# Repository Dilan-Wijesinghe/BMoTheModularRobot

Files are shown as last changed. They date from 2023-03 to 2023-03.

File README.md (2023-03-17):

# BMo
Winter Project for my MS in Robotics Winter Quarter!

Video Demonstration (https://www.youtube.com/watch?v=KZacVYFTs9U)

All Modules

### Project Description
BMo is a modular robot consisting of three distinct modules, the brain (BMo), motor (MMo), and hinge (HMo) modules. By connecting these modules in a different configurations, BMo can transform into several different robots. BMo was inspired by the modular robotics kits I had as a child, and was a challenge to myself to do a very intensive hardware project with almost zero experience.

This repository contains the code accompanying BMo.
It also includes the final CAD files I used to create each module.

BMo in a 'Crab' Configuration

### Hardware
Below is the boards used, and the magnetic connector that made everything possible
* [Adafruit Feather RP2040](https://www.adafruit.com/product/4884)
* [Adafruit Feather ESP32](https://www.adafruit.com/product/3591)
* [Magnetic Pogo Pin](https://www.adafruit.com/product/5413)

### Uploading Code
To upload code onto the RP2040 boards, hold down the BOOTSEL button while inserting a USB-C from your PC.
This should pop open a drive called 'RPI-RP2' onto your PC. From here you can use the Arduino IDE to upload the 
code. 

Note the pins used during setup(), as these pins determine where communication is sent. 
SCL and SDA are used for i2c communication, while pins 26 or 20 are used for servo control.

### Central.io (Brain)
This file contains code necessary for running the central or 'brain' of BMo. It sends i2c messages received 
from the Serial port in order to communicate with the rest of the modules. 
Once the code is loaded, use `screen` or the serial port in the Arduino IDE to send messages.

### Sender.io (Wireless Serial)
This file contains half of the code for the central 'brain' and allows wireless communication through the
ESP32 NOW peer-to-peer protocol. This half uses the serial port to send commands wirelessly to a receiver
board located inside BMo. To connect the sender to the receiver, you need to have both of their MAC
addresses, which can be found by using `WiFi.macAddress()`

### Receiver.io (Wirless Brain)
The file contains the other half of the central 'brain'. It takes the commands from the sender and 
sends them to any of the connected peripherals along its i2c bus. 

### Peripheral.io (Motor Module)
This file contains code necessary for running the peripheral or main 'motor' module, MMo. It receives
i2c messages from the brain and moves according to the given command. By default, `i` moves the servo inside
the module clockwise, while `k` moves it counter-clockwise. Pressing `j` will stop the motor.

To remap, modify the if statements to your desired mapping.

### HMo.io (Hinge Module)
This file contains code necessary for running the peripheral module, HMo. In the same way MMo receives and interprets messages, so
does HMo. Currently, the `e`, `w`, and `q` are mapped to one 0, 90, and 180 degrees.

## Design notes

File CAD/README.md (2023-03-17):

### Building BMO
This folder contains the necessary files in order to build each module. Each piece is laser 
cut on a 1/8" acrylic piece and press-fit together. For additional strength, I added super glue 
to a few of the walls, but left at least two openings to fix any internal electrical issues.

Each of the subfolders contains images of the layout of each module, which can serve 
as a guide to put them all together.

Let's get building!

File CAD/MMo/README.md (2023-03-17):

### MMo Build Guide
In order to construct MMo, go through a similar process as 
BMo and HMo by cutting out each part on your laser cutter. Each piece connects together
as depicted in the image below. 

MMoSkeletonCropped

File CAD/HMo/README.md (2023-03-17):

### HMo Build Guide
In order to construct HMo, go through a similar process as 
BMo and cut out each part on your laser cutter. Each piece connects together
as depicted in the image below. 

HMoSkeletonCropped

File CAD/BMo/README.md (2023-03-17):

### BMo Build Guide
In order to construct BMo, cut out each part on your laser cutter. You will need to
cut out the Bot/Top wall twice, as well as the Right/Left wall, since they are identical.
Here is how they should look. 

BMoSkeletonCropped

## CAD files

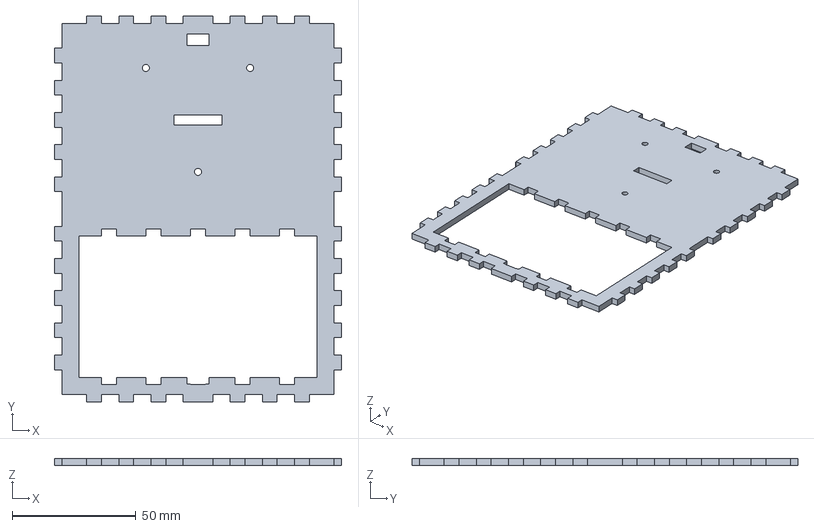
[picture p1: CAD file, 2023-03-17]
CAD/BMo/Bmo Top.step
116.0 x 156.0 x 3.00 mm

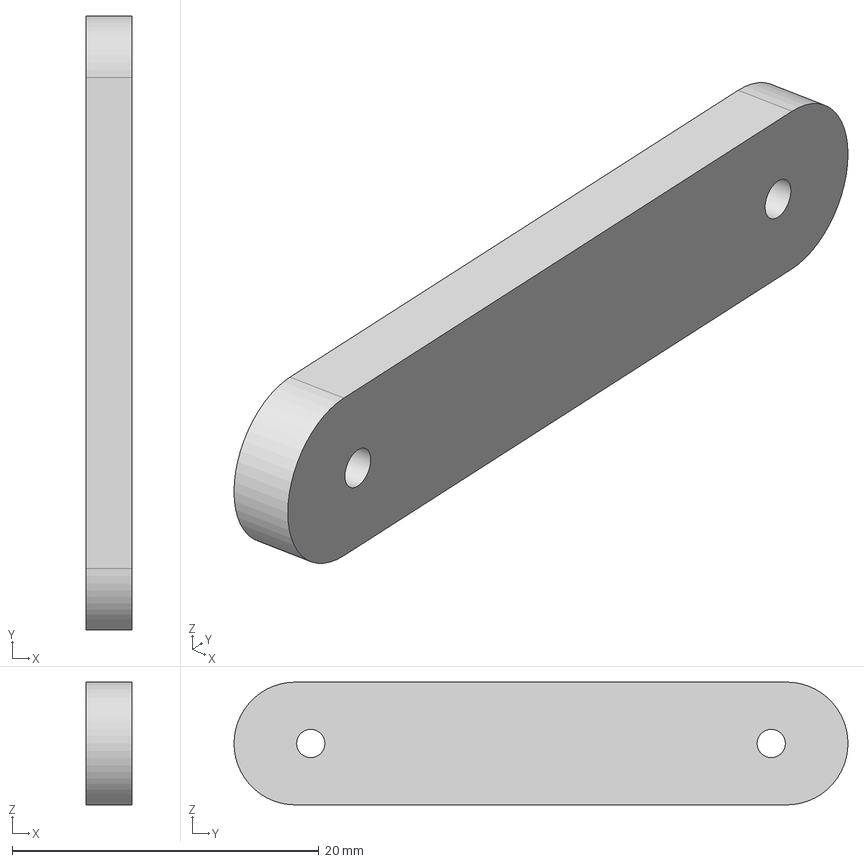
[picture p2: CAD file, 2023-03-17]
CAD/HMo/Hmo_Bracket.step
3.00 x 40.0 x 8.00 mm

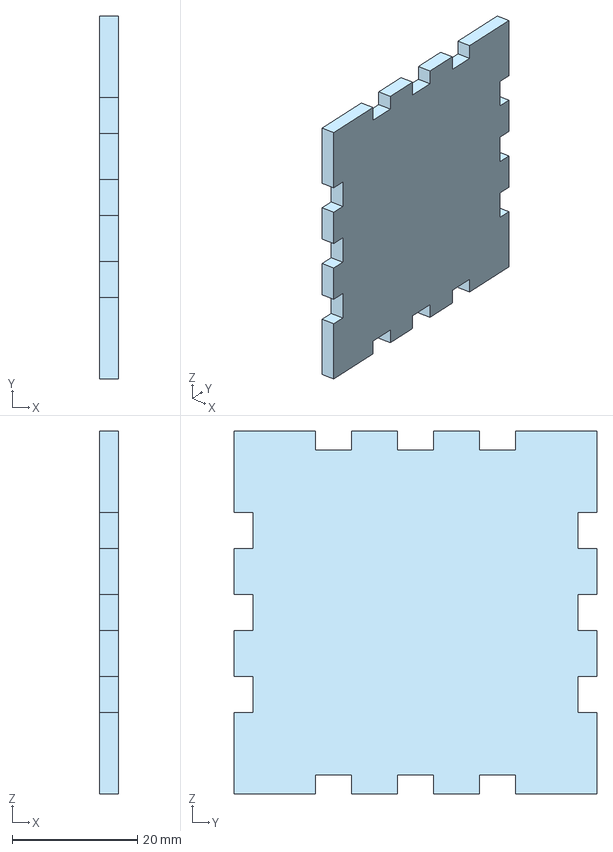
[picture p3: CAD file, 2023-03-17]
CAD/MMo/Mmo_right_wall.step
3.00 x 58.0 x 58.0 mm

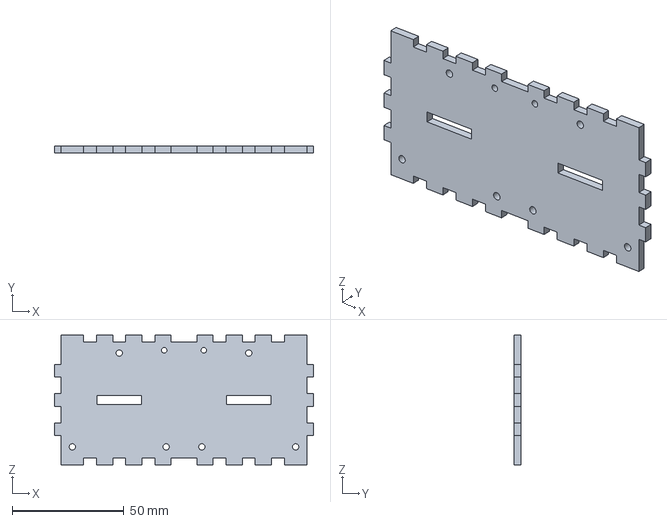
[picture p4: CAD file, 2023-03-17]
CAD/BMo/Bmo BotTop Wall.step
116.0 x 3.00 x 58.0 mm

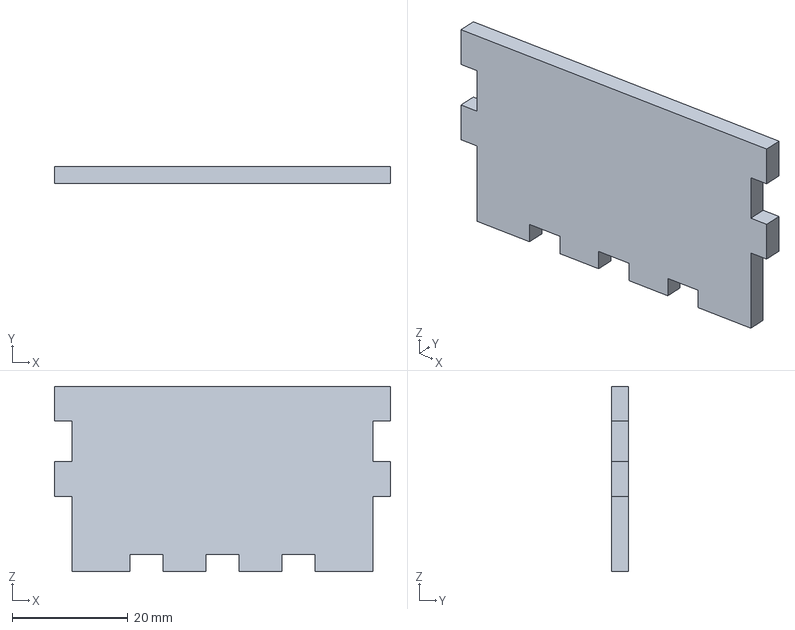
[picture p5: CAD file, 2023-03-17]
CAD/HMo/Hmo_Bot_Wall.step
58.0 x 3.00 x 32.0 mm

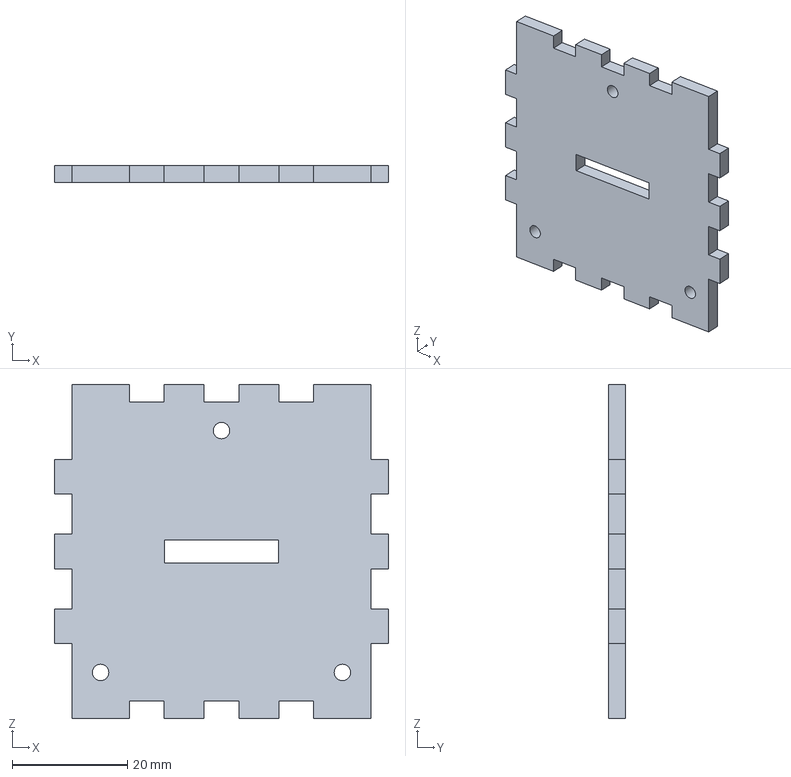
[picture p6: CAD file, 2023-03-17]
CAD/MMo/Mmo_top_wall.step
58.0 x 3.00 x 58.0 mm

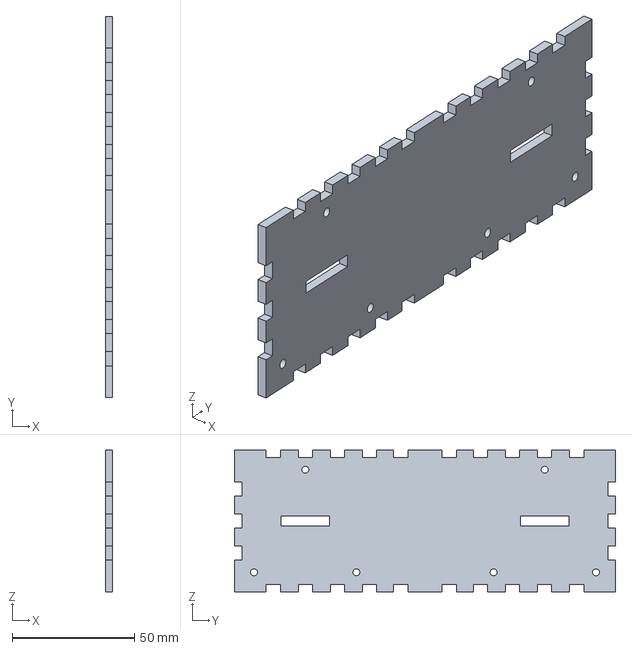
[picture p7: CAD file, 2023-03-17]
CAD/BMo/Bmo RightLeft Wall.step
3.00 x 156.0 x 58.0 mm

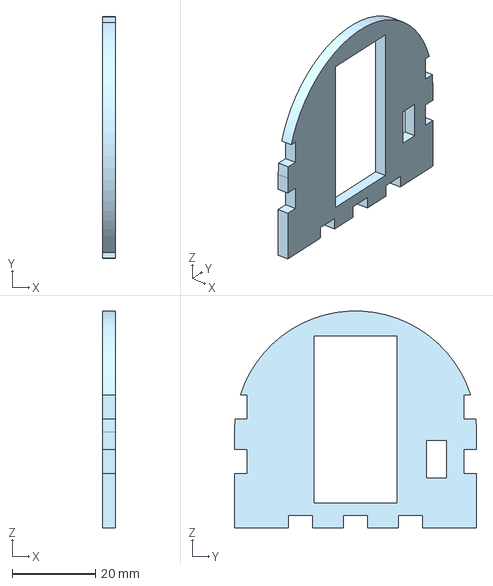
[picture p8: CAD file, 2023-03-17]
CAD/HMo/Hmo_Left_Wall.step
3.00 x 58.0 x 52.0 mm

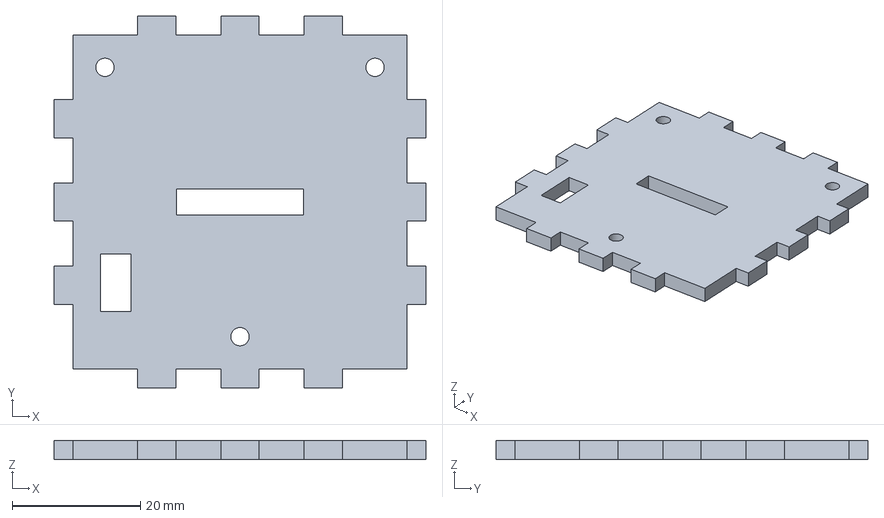
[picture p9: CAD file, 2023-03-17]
CAD/MMo/Mmo_bot.step
58.0 x 58.0 x 3.00 mm

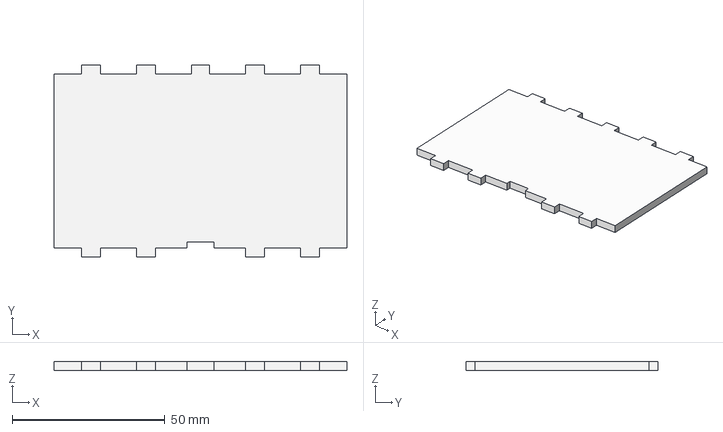
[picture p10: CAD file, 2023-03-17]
CAD/BMo/Bmo Face.step
96.0 x 63.0 x 3.00 mm

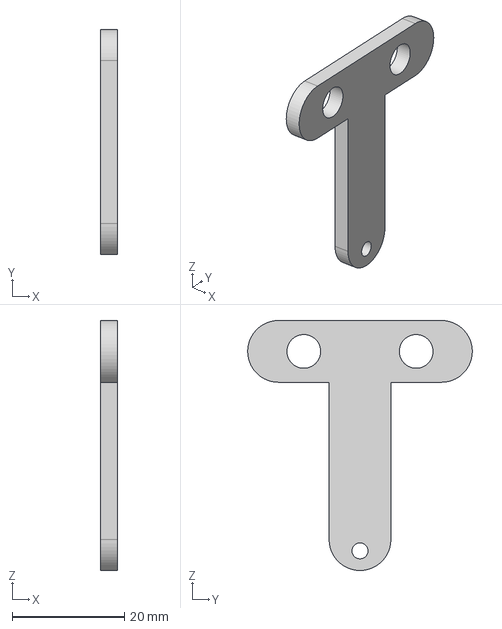
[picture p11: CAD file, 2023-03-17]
CAD/HMo/Hmo_Arm.step
3.00 x 40.0 x 44.5 mm

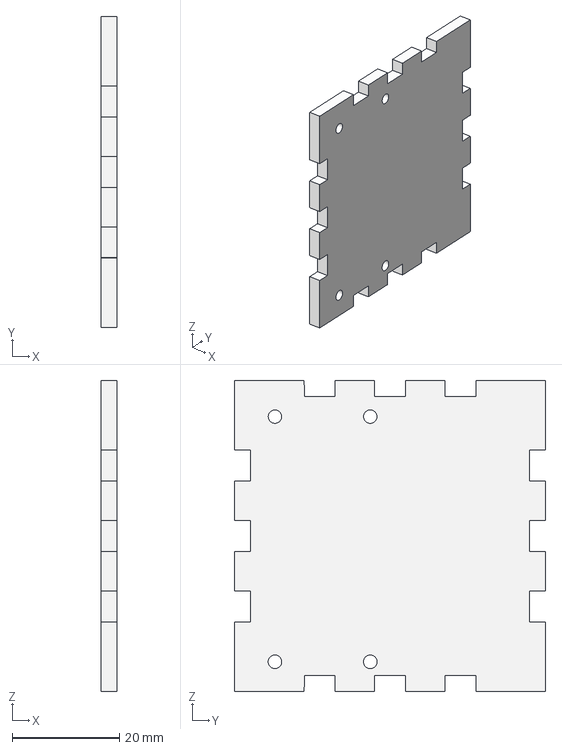
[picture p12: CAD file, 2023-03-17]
CAD/MMo/Mmo_left_wall.step
3.00 x 58.0 x 58.0 mm

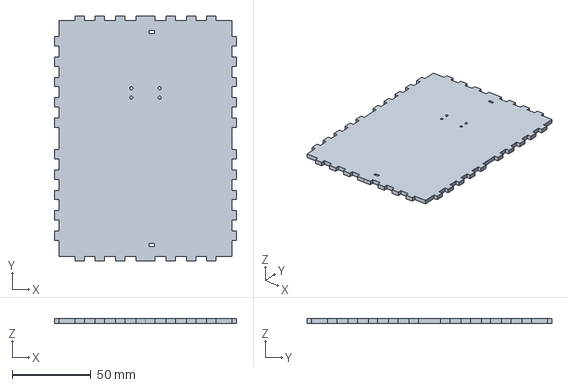
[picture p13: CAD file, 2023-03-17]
CAD/BMo/Bmo Bot.step
116.0 x 156.0 x 3.00 mm

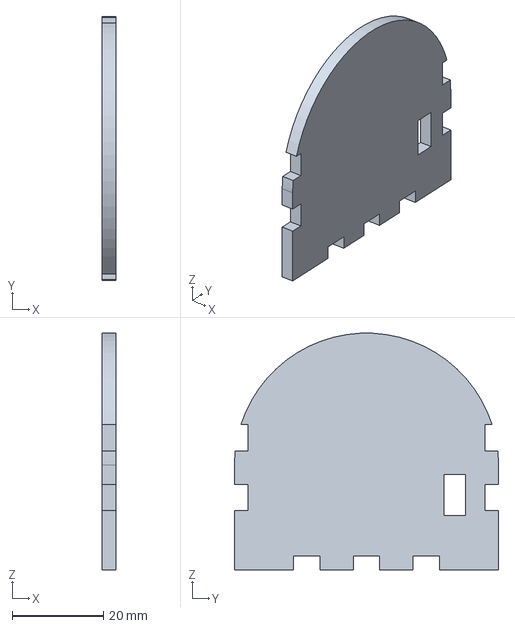
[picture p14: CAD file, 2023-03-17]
CAD/HMo/Hmo_Right_Wall.step
3.00 x 58.0 x 52.0 mm

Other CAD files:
CAD/MMo/Mmo_bot_wall.step
CAD/HMo/Hmo_Bot.step
CAD/MMo/Mmo_top.step
CAD/HMo/Hmo_Top_Wall.step

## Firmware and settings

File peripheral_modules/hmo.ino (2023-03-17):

// Include the required Wire library for I2C
#include <Wire.h>
#include <Servo.h>

Servo servo;  // servo controller (multiple can exist)

int pin = 20;  // PWM pin for servo control

void setup() {
  Serial.begin(115200);  // start serial monitor
  Wire.setSDA(0);        // Set i2c communication to pins 0 and 1
  Wire.setSCL(1);
  Wire.begin(0x42);  // set address of peripheral as 0x38
  Wire.onReceive(receiveEvent);
  servo.attach(pin);  // start servo control
  servo.write(90);    // move servo to 90 degrees
  Serial.println("0x42 Booting Up!");
  delay(2000);
  servo.detach();
}

char l = ' ';
void loop() {
  // Serial.println("I am alive");
  if (Serial.available()) {
    l = Serial.read();
    if (l == 'c') {
      servo.attach(pin);
      servo.write(0);
      delay(500);  // delay(2000);
    }

    if (l == 'x') {
      servo.attach(pin);
      servo.write(90);
      delay(500);  // delay(2000);
    }

    if (l == 'z') {
      servo.attach(pin);
      servo.write(180);
      delay(500);  // delay(2000);
    }
    if (l == 'v') {
      servo.detach();
    }
  }
  // servo.detach();
}

char c = ' ';
void receiveEvent(int howMany) {
  while (Wire.available()) {  // loop through all but the last0
    c = Wire.read();          // receive byte as a character
    Serial.println((String) "Command Sent is: " + c);
    if (c == 'e') {
      servo.attach(pin);
      servo.write(0);
      delay(500);
    }

    if (c == 'w') {
      servo.attach(pin);
      servo.write(90);
      delay(500);
    }

    if (c == 'q') {
      servo.attach(pin);
      servo.write(180);
      delay(500);
    }
    servo.detach();
  }
}

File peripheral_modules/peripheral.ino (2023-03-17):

// Include the required Wire library for I2C
#include <Wire.h>
#include <Servo.h>

Servo servo1;
int pos = 0;
void setup() {
  Serial.begin(115200);
  // Set the i2c SDA and SCL ports
  Wire.setSDA(0);
  Wire.setSCL(1);
  Wire.begin(0x34);  // 0x30, 0x34, 0x46, 0x50
  Wire.onReceive(receiveEvent);
}

// Buffer to write into
static char buff[100];
void loop() {
}


// }
char c = 'j';
void receiveEvent(int howMany) {
  // Serial.print(c);       // print the character
  while (Wire.available())  // loop through all but the last0

    c = Wire.read();  // receive byte as a character
  // Serial.print(c);       // print the character
  Serial.println((String) "Command Sent is: " + c);
  if (c == 'i') {
    servo1.attach(26);
    servo1.write(180);
  }

  if (c == 'k') {
    servo1.attach(26);
    servo1.write(0);
  }

  if (c == 'j') {
    servo1.detach();
  }
  // Serial.println(c);
}
